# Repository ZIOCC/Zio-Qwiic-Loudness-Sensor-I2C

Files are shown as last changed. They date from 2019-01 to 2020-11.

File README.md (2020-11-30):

# Zio Qwiic Loudness Sensor I2C

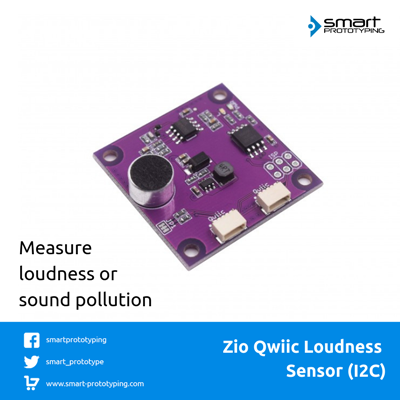
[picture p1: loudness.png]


> This product can be available for purchase [here](https://www.smart-prototyping.com/Zio-Qwiic-Loudness-Sensor-I2C).

Check this [RPI Library](https://github.com/l33tllama/Zio-Loudness-Sensor-Python). 

#### Description

In order to create an environment sensor kit, we should not forget a loudness sensor that can measure the noise level. So, this is a Qwiic version (I2C) of Loudness sensor that can output ADC value (0-1023) to tell you the level of the noise. Also you can use this ADC value into other project, like a sound sensor.

We use an MCU (ATTINY85-20SU) as gateway to turn it into an I2C device. we’ve put the necessary code into it, in case you are interested in this part, check our github channel here. 

The loudness value strongly depends on the distance between the sound source and sensor. For example, if you are playing music with your smartphone, when you place the sensor in close proximity to the phone (within 20cm), with low volume settings, the sensor would output a 500 value, but if you put the sensor 2 meters away, the output value might be 200-300 even when the volume is set to very high. It is similar like the microphone in the KTV. 

This is a [Qwiic compatible](https://www.smart-prototyping.com/Qwiic.html) module, which means you can use [Qwiic cable](https://www.smart-prototyping.com/zio-cables) to quickly connect to other qwiic devices, with no soldering and jumper wire connecting!

#### Specification

* Gateway MCU: ATTINY85-20SU
* I2C address: 0x07- 0x78 (Default:0x38)
* Loudness rate Range: 0-1023
* Dimension: 36.3 x 36.5mm
* Weight: 7.3g

#### Links

* [PCB Source file](https://github.com/ZIOCC/Zio-Qwiic-Loudness-Sensor-I2C)
* [PCB schematic](https://github.com/ZIOCC/Zio-Qwiic-Loudness-Sensor-I2C/blob/master/zio%20qwiic%20loudness%20sensor%20schematic.pdf)
* [Demo code](https://github.com/ZIOCC/Zio-Qwiic-Loudness-Sensor-I2C/tree/master/Codes/Qwiic%20Loudness%20Sensor%20Examples)
* [Gateway firmware](https://github.com/ZIOCC/Zio-Qwiic-Loudness-Sensor-I2C/tree/master/Codes/Qwiic_Loudness_Sensor_Firmware/Qwiic_Loudness_Sensor_Firmware)

> ###### About Zio
> Zio is a new line of open sourced, compact, and grid layout boards, fully integrated for Arduino and Qwiic ecosystem. Designed ideally for wearables, robotics, small-space limitations or other on the go projects. Check out other awesome Zio products [here](https://www.smart-prototyping.com/Zio).

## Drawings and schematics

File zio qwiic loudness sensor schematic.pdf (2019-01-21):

7.8V
+3V3

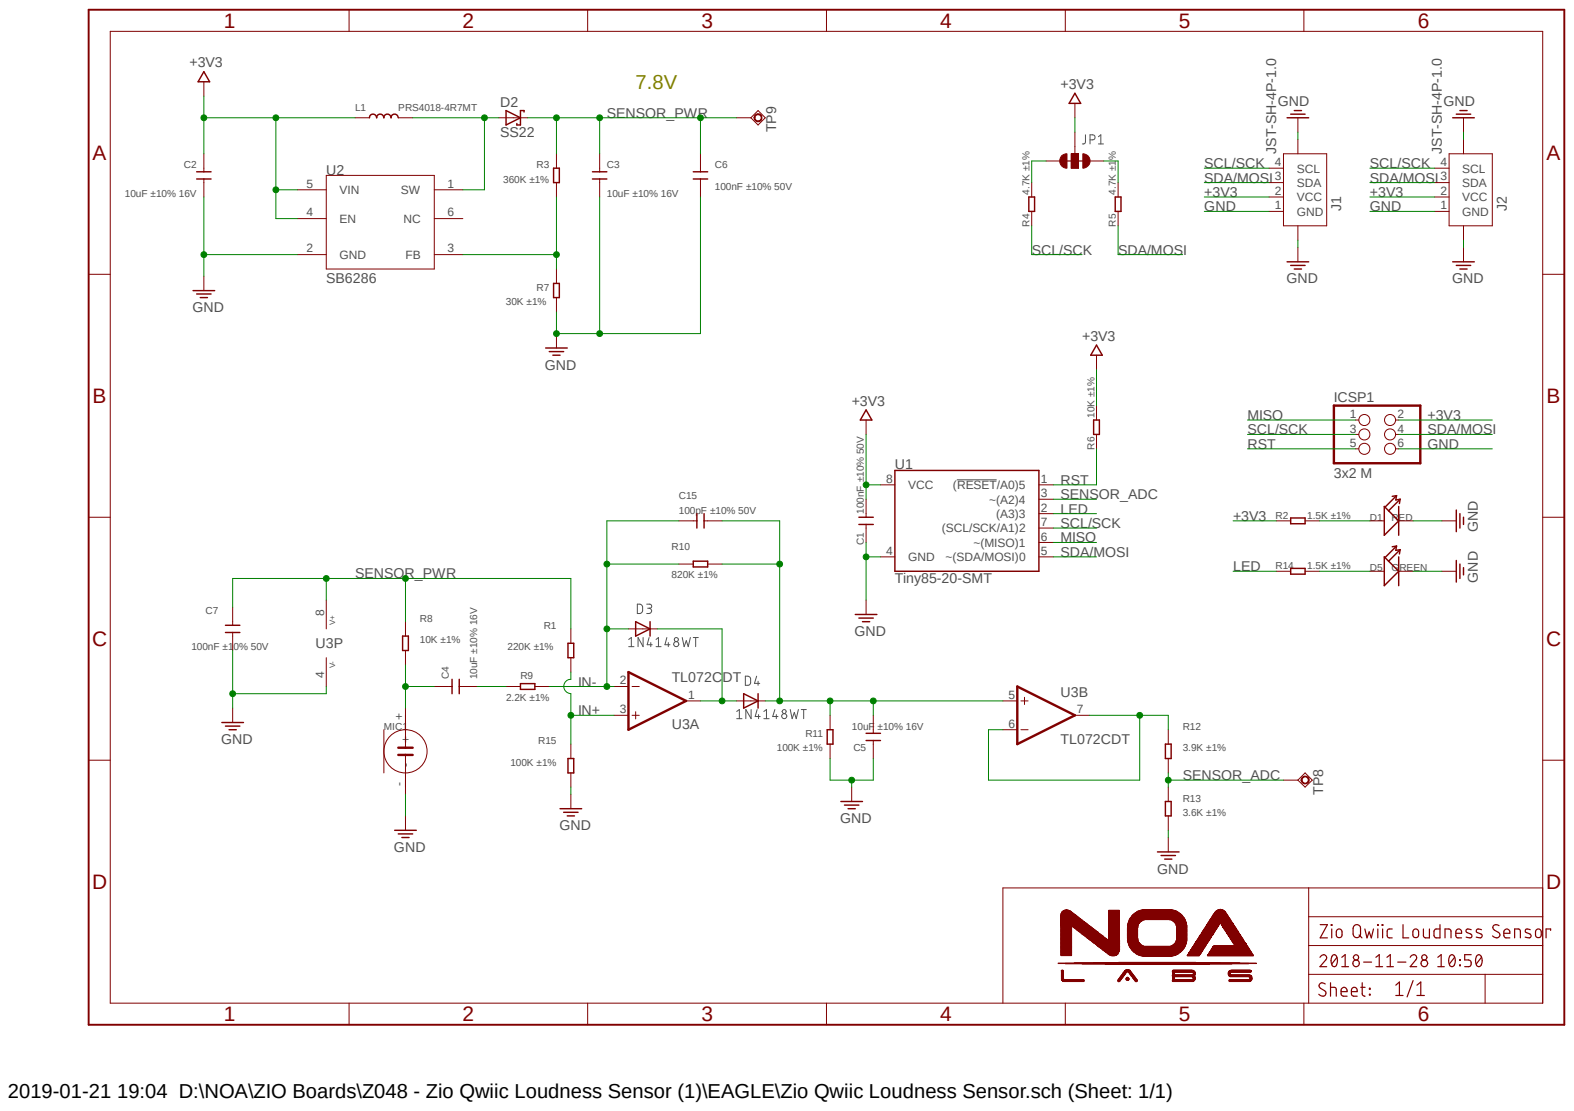
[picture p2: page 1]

2019-01-21 19:04 D:\NOA\ZIO Boards\Z048 - Zio Qwiic Loudness Sensor (1)\EAGLE\Zio Qwiic Loudness Sensor.sch (Sheet: 1/1)

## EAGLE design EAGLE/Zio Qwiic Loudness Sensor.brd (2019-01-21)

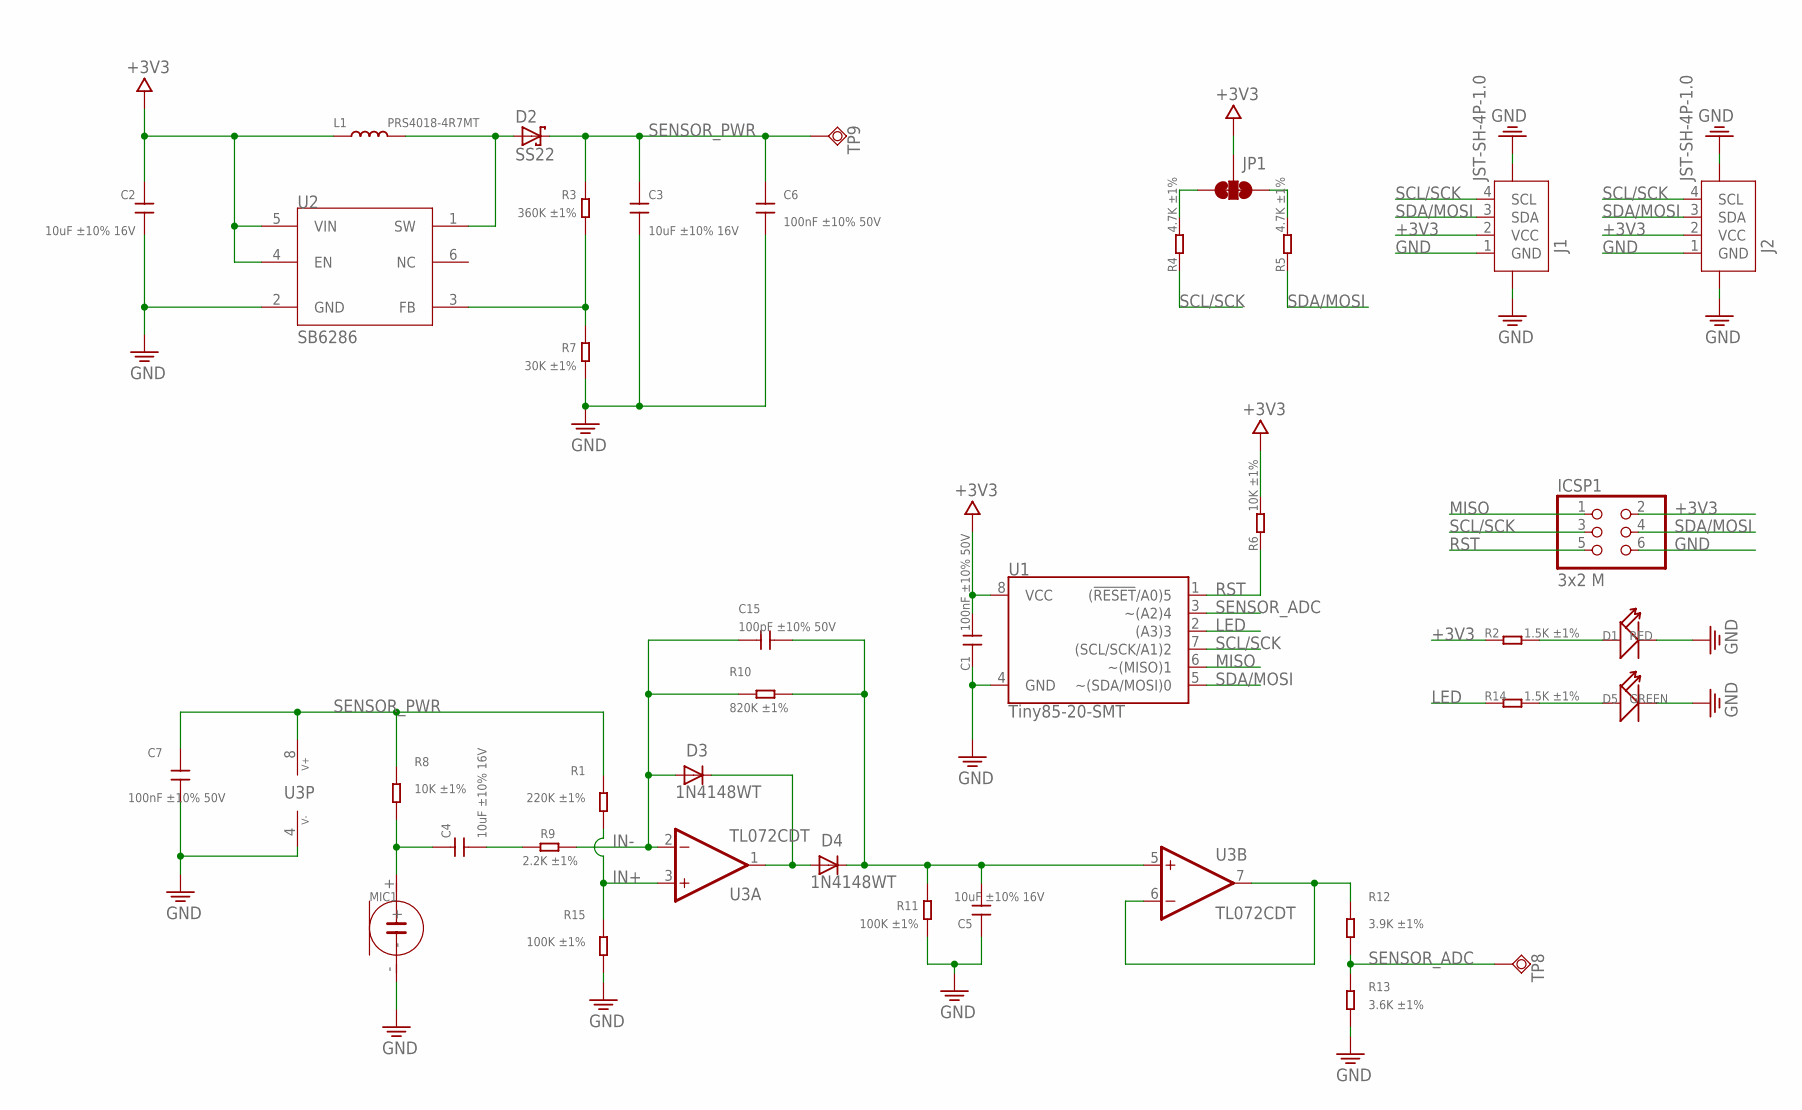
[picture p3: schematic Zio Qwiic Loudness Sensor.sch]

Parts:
C1, C6, C7: 100nF ±10% 50V; C0603
C2: 10uF ±10% 16V; C0603
C3, C4, C5: 10uF ±10% 16V; 0603
C15: 100pF ±10% 50V; C0603
D1: RED; LED-0603
D2: SS22; SMA
D3, D4: 1N4148WT; SOD523
D5: GREEN; LED-0603
ICSP1: 3x2 M; 2X03
J1, J2: JST-SH-4P-1.0; JST-SH-4P
JP1: SMT-JUMPER_3_2-NC_TRACE
L1: PRS4018-4R7MT; L4030
MIC1: MIC-2P(EAO-9745-PFA-C1033-28-008); MIC2-D9.7XH4.5MM
R1: 220K ±1%; R0603
R2, R14: 1.5K ±1%; R0603
R3: 360K ±1%; R0603
R4, R5: 4.7K ±1%; R0603
R6, R8: 10K ±1%; R0603
R7: 30K ±1%; R0603
R9: 2.2K ±1%; R0603
R10: 820K ±1%; R0603
R11, R15: 100K ±1%; R0603
R12: 3.9K ±1%; R0603
R13: 3.6K ±1%; R0603
TP8: TPSQTP08R; TP08R
TP9: TPSQTP12R; TP12R
U1: Tiny85-20-SMT; SO08-EIAJ_MCU
U2: SB6286; SOT23-6
U3: TL072CDT; SO08

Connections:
+3V3: C1.2, C2.2, ICSP1.2, J1.2 (VCC), J2.2 (VCC), JP1.2, L1.1, R2.1, R6.2, U1.8 (VCC), U2.4 (EN), U2.5 (VIN)
GND: C1.1, C2.1, C3.1, C5.2, C6.1, C7.1, D1.-, D5.-, ICSP1.6, J1.1 (GND), J1.NC1 (5), J1.NC2 (6), J2.1 (GND), J2.NC1 (5), J2.NC2 (6), MIC1.-, R7.1, R11.1, R13.1, R15.1, U1.4 (GND), U2.2 (GND), U3.4 (V-)
IN+: R1.1, R15.2, U3.3 (+IN)
IN-: C15.2, D3.2 (A), R9.1, R10.1, U3.2 (-IN)
LED: R14.1, U1.2 ((A3)3)
MISO: ICSP1.1, U1.6 (~(MISO)1)
unnamed: D1.+, R2.2
unnamed: R12.2, U3.6 (-IN), U3.7 (OUT)
unnamed: C5.1, C15.1, D4.1 (K), R10.2, R11.2, U3.5 (+IN)
unnamed: R3.1, R7.2, U2.3 (FB)
unnamed: D5.+, R14.2
unnamed: JP1.3, R4.2
unnamed: D3.1 (K), D4.2 (A), U3.1 (OUT)
unnamed: JP1.1, R5.2
unnamed: C4.2, MIC1.+, R8.1
unnamed: C4.1, R9.2
RST: ICSP1.5, R6.1, U1.1 ((!RESET!/A0)5)
SCL/SCK: ICSP1.3, J1.4 (SCL), J2.4 (SCL), R4.1, U1.7 ((SCL/SCK/A1)2)
SDA/MOSI: ICSP1.4, J1.3 (SDA), J2.3 (SDA), R5.1, U1.5 (~(SDA/MOSI)0)
SENSOR_ADC: R12.1, R13.2, TP8.TP, U1.3 (~(A2)4)
SENSOR_PWR: C3.2, C6.2, C7.2, D2.P$1 (C), R1.2, R3.2, R8.2, TP9.TP, U3.8 (V+)
SW: D2.P$2 (A), L1.2, U2.1 (SW)

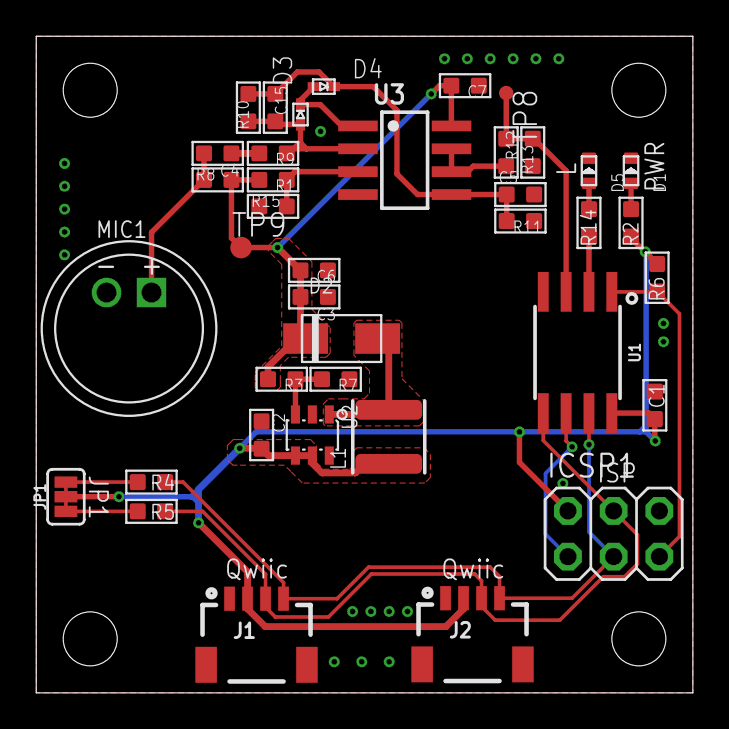
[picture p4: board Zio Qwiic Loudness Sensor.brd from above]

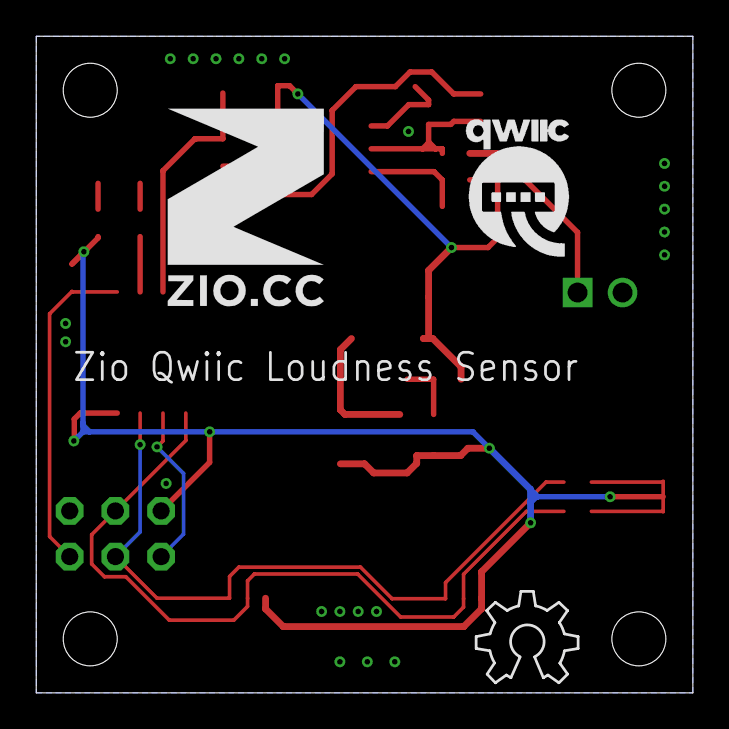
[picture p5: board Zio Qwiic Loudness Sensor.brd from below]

Board: 2 copper layers, 36.5 x 36.5 mm, 42 parts (3 on the bottom side), 22 nets.

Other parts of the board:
U$3: 11MM
U$4: QWIIC-LOGO-LARGE
U$5: OSHW_6X200_NOTEXT

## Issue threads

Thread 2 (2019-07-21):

Does not work with Arduino ESP8266?

Humancell, 2019-07-21:
Hello,

I really like this board - ZIO QWIIC LOUDNESS SENSOR (I2C) - and we want to use it in one of our products.  But it will not work with the Arduino ESP8266 for some reason.  I've spent the last several hours attempting to see what it might be, but can not locate the problem.

My board is working with an Arduino UNO.

When I attach it to the ESP8266 it does not work.  I have many other I2C devices that work just fine with this ESP8266, so it is not the ESP8266.

When I run your Example1-Basic_Reading it does discover the board at I2C address 0x38.  If I comment out the get_value(); in loop, the LED *does* blink.  So I2C *writes* are working perfectly.  When it goes to read however the read fails.

The first time through the loop Wire.endTransmission returns 0 (which is good!) but Wire.requestFrom() also returns 0 ... which means no bytes were read.  On all subsequent calls to get_value(); the Wire.endTransmission returns 0x04 ... other error.

It seems that maybe there is an issue with the ESP8266 Wire library talking with your device ... which uses the TinyWire library?

Do you have any suggestions or ideas?

Humancell, 2019-07-21:
As I have done more research on this issue, numerous people talk about having to update the bootloader of the ATTiny85 to run at 8Mhz ... what speed do you program these to run at?

Humancell, 2019-08-05:
Hello?  If I can't solve this I really can't buy more of these to integrate into our product.  Any suggestions on how to debug/repair this?

Humancell, 2020-01-08:
I forgot that I had solved this!

It turns out that you need to enable some I2C clock stretching for the ESP8266 to work with this board.

I used the lines:

```
  Wire.begin();
  Wire.setClock(100000L); //Increase to fast I2C speed!
  Wire.setClockStretchLimit(1000); // Allow for 1000us of clock stretching
```
And now everything works perfectly!

Closed 2020-01-08.

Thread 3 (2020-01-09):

I2C Bus stops responding after several minutes?

Humancell, 2020-01-09:
I have been running your demo application, and after several minutes (3-5) of operation, the sound level board stops responding.

If I power cycle the board, it will return and continue responding for a while ... and then it locks up and stops responding.

This is occurring with several of these boards that I bought from you?

Any ideas?

AlexChuSmartPrototyping, 2020-07-07:
Hi, there, can you share me more details about this issue so I can repeat this issue on my side? Do you mean the other loudness sensor boards also had this issue?

24601, 2020-10-01:
Yeah, same here....especially when the display is connected, it locks up hard after just a few seconds.

AlexChuSmartPrototyping, 2020-11-16:
Hi I tested the board again with a display module, it works well.
Which board are you using and how is the connection looks like? Could you share your code and a picture here or send to us an email? So we can repeat the issue and solve it.
Thanks.

>
>
> Yeah, same here....especially when the display is connected, it locks up hard after just a few seconds.

AlexChuSmartPrototyping, 2020-11-17:
I could repeat this issue on my side only by connecting the module to 5V power and I2C, the module did locked up. Could you try with 3.3V power and I2C? The Qwiic should always run on 3.3V.

AlexChuSmartPrototyping, 2020-11-18:
We did some additional testing and comparison between 3.3V and 5V on the power and I2C bus and these are our results:

Power             Voltage | I2C Voltage | Data Refresh Rate | Result
-- | -- | -- | --
3.3V | 3.3V | Slow (~3/s) | OK
3.3V | 3.3V | Fast (~30/s) | OK
3.3V | 5.0V | Slow (~3/s) | OK
3.3V | 5.0V | Fast (~30/s) | Sometimes not working
5.0V | 5.0V | Slow (~3/s) | not OK
5.0V | 5.0V | Fast (~30/s) | not OK

Can you maybe double-check if you are getting similar results? If yes then we know it is related to the power voltage and can add that to the product description (or consider to avoid that hardware wise).

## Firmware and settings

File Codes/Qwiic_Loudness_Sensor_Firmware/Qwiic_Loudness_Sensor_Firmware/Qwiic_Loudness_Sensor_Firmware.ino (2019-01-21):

/******************************************************************************
  Zio Qwiic Loudness Sensor Firmware
  Harry
  September 25, 2018

  This is the firmware on the Zio Qwiic Loudness Sensor. The default I2C Address is
  0x38;

******************************************************************************/
#include <TinyWire.h> //https://github.com/lucullusTheOnly/TinyWire
#include <EEPROM.h>

#define LED_PIN   3
#define ADC_PIN   A2
#define SETTING_LOCATION_ADDRESS	1

volatile byte qwiicAddress  =    0x38; //default

#define COMMAND_LED_OFF 			0x00
#define COMMAND_LED_ON 			0x01
#define COMMAND_CHANGE_ADDRESS 		0x03
#define COMMAND_GET_VALUE 				0x05
#define COMMAND_HAS_BEEN_CHECKED 	0x99

volatile byte command = COMMAND_HAS_BEEN_CHECKED;
volatile byte address = COMMAND_HAS_BEEN_CHECKED;
uint16_t ADC_VALUE=0;
uint8_t  ADC_VALUE_H=0,ADC_VALUE_L=0;

void setup() {
  //Read EEPROM, is it empty (0xFF)? or does it have a value?
  qwiicAddress =  EEPROM.read(SETTING_LOCATION_ADDRESS);
  if (qwiicAddress == 0xFF) {
    //EEPROM has never been written before, use the default address 0x38.
    qwiicAddress = 0x38; //default
  }

  TinyWire.begin(qwiicAddress);
  TinyWire.onReceive(receiveEvent); // register event
  TinyWire.onRequest(onI2CRequest);
}

void loop() {
}

/*========================================================*/
//        ISR
/*========================================================*/

// When the master initiates a command and data to slave
//		ie) the master says 0x01, then sends a 1, means command: 0x01 then the slave listens for the next thing, which is the LED state 1
void receiveEvent(int bytesReceived) {
  byte count = 0;
  while (TinyWire.available() > 0) {
    if (count == 0) {
      command = TinyWire.read();

      if (command == COMMAND_LED_ON) {
        digitalWrite(LED_PIN, HIGH);
        command = COMMAND_HAS_BEEN_CHECKED;
      }
      else if (command == COMMAND_LED_OFF) {
        digitalWrite(LED_PIN, LOW);
        command = COMMAND_HAS_BEEN_CHECKED;
      }
    }
    else if (count == 1) {
      if (command == COMMAND_CHANGE_ADDRESS) {
        byte address = TinyWire.read();

        if (address > 0x07 && address < 0x78) {
          //valid address, update and save to EEPROM
          qwiicAddress = address;

          EEPROM.write(SETTING_LOCATION_ADDRESS, qwiicAddress);
          TinyWire.begin(qwiicAddress);
        }
      }
    }
    else {
      TinyWire.read(); //read the data coming in but ignore it.
    }
    count++;
  }
}// end of receive ISR

//When the master requests data from the slave, this
//    ISR is triggered.

void onI2CRequest() {
   if (command == COMMAND_GET_VALUE) {
    ADC_VALUE=analogRead(ADC_PIN);
    ADC_VALUE_L=ADC_VALUE;
    ADC_VALUE_H=ADC_VALUE>>8; 
    TinyWire.send(ADC_VALUE_L);  
    TinyWire.send(ADC_VALUE_H);
    command = COMMAND_HAS_BEEN_CHECKED;
  }
}

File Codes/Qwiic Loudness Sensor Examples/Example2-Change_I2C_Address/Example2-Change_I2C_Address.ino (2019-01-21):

/******************************************************************************
  Zio Qwiic Loudness Sensor Example 2 - Change I2C Address
  Harry
  September 25, 2018

  This sketch demonstrates how to change the I2C Address
  of the Zio Qwiic Loudness Sensor. The new address will be saved to the
  Sensor's EEPROM.

  The factory default slave address is 0x38.

  Note: If the Zio Qwiic Loudness Sensor is connected but unresponsive, 
  try Example 3 - I2C_Scanner to find the current address of the Sensor.

  Only valid address can be saved to the Sensor's EEPROM. If an invalid address is
  sent, the Sensor will ignore the address change without notifying the user.

******************************************************************************/
#include <Wire.h>
#define COMMAND_LED_OFF 				  0x00
#define COMMAND_LED_ON 				    0x01
#define COMMAND_CHANGE_ADDRESS 			0x03

volatile byte qwiicAddress = 0x38;     //Default Address

void setup() {
  Serial.begin(9600);
  Serial.println("Zio Qwiic Loudness Sensor Master Awake");
  Wire.begin(); // join the I2C Bus

  Wire.beginTransmission(qwiicAddress); // transmit to device
  //check here for an ACK from the slave
  if (Wire.endTransmission() != 0 ) {
    Serial.println("Check Connections. Slave not found.");
  }

  Serial.println("Zio Qwiic Loudness Sensor found!");

  ledOn(); // Turn on the LED (at address 0x28)
  delay(1000);
  byte error = changeAddress(0x29); // Change the Sensor's address to 0x29
  ledOff(); // Turn off the LED (at address 0x29)
  delay(1000);
  changeAddress(0x00); // Try to change address to Invalid Address.

  if (error != true) {
    Serial.println("!!!!! invalid address" );
  }
  Serial.println("success");
}

void loop() {
}
// changeAddress() takes a 7 bit I2C Address
// and writes it to the Sensor. This function
// checks to see if the address is between
// 0x07 and 0x78. If valid, the new address is
// saved to the Sensor's EEPROM. If not valid
// address is not changed and is ignored.
// This function returns true if successful and
// false if unsuccessful.
boolean changeAddress(byte address) {
  Wire.beginTransmission(qwiicAddress);
  //check here for an ACK from the slave
  if (Wire.endTransmission()  != 0) {
    Serial.println("Check Connections. No slave found.");
    return (false);
  }

  //check if valid address.
  if (address < 0x07 || address > 0x78) {
    Serial.println("Invalid I2C address");
    return (false);
  }
  //valid address
  Wire.beginTransmission(qwiicAddress);
  Wire.write(COMMAND_CHANGE_ADDRESS);
  qwiicAddress = address;
  Wire.write(qwiicAddress);
  Wire.endTransmission();
  return (true); //Success!
}

// ledOn() turns on the relay at the SLAVE_ADDRESS
// Checks to see if a slave is connected and prints a
// message to the Serial Monitor if no slave found.
void ledOn() {
  Wire.beginTransmission(qwiicAddress);
  Wire.write(COMMAND_LED_ON);
  Wire.endTransmission();
}

// ledOff() turns off the relay at the SLAVE_ADDRESS
// Checks to see if a slave is connected and prints a
// message to the Serial Monitor if no slave found.
void ledOff() {
  Wire.beginTransmission(qwiicAddress);
  Wire.write(COMMAND_LED_OFF);
  Wire.endTransmission();
}
